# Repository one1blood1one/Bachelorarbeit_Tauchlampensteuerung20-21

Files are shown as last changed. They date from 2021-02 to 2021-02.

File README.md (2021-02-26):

Dieses Repository gehört zur Bachelorarbeit von Dennis Sitnic. 
Es enthält (nach der Fertigstellung) folgende Dateien:

**Unterlagen:**
- Bachelorarbeit PDF
- Präsentation der Arbeit
- Gebrauchsanleitung 

**Breakoutboard:**
- Eagle Daten
- Gerberdaten
- BOM

**Gesamtschaltung:**
- Eagle Daten
- Gerberdaten
- BOM

**Software:**
- Microcontroller Code
- Initialprogrammierung shell script

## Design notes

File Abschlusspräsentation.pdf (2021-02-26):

## Wintersemester 2020-21

Dennis Sitnic | 26.02.2021

# Abschlusspräsentation

# Entwicklung einer µC-Steuerung für Halogenbrenner mit LIB Management

Seite 2/31
26.02.2021

Entwicklung einer Tauchlampensteuerung Dennis Sitnic

# Gliederung

# 1. Einführung

# 2. Vorgehen und Ergebnis

## 1. Breakoutboard (BMS) 2. Steuerteil (µC) 3. Machbarkeitstests 4. Gesamtschaltung

# 3. Weiterführende Arbeiten

# 1 Einführung

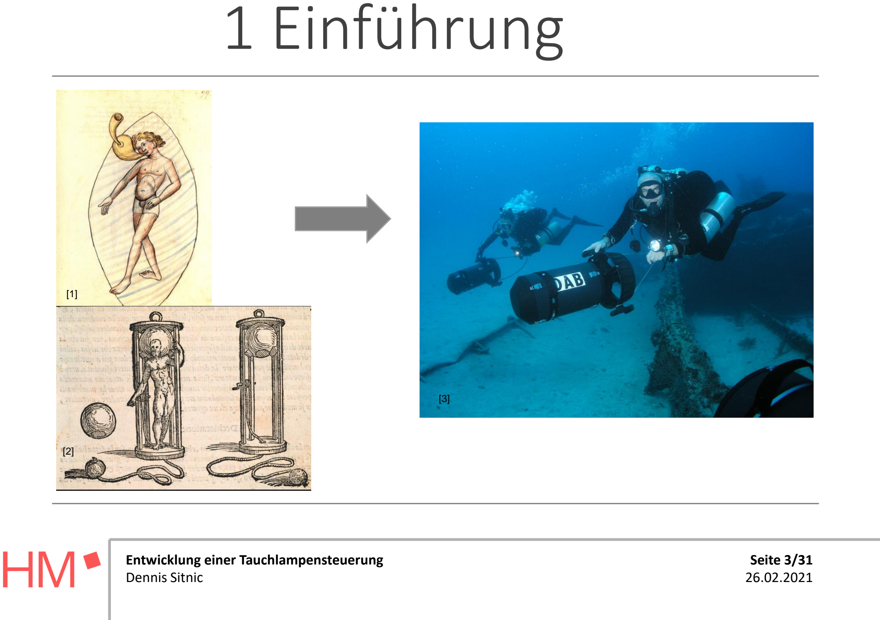
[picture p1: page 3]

Seite 3/31

Entwicklung einer Tauchlampensteuerung

[1]

[2]

[3]

Seite 4/31

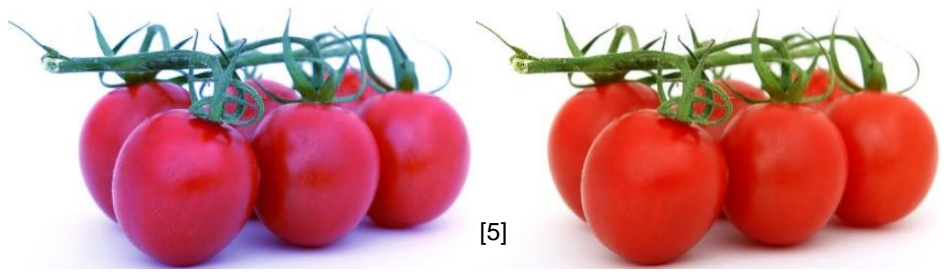
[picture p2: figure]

Entwicklung einer Tauchlampensteuerung

# 1 Einführung

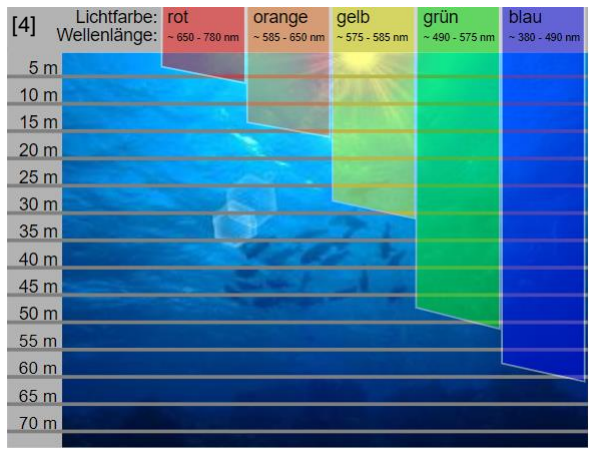
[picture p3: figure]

⚫ | rotes Licht dringt weniger tief ein
⚫ | Halogenlampen strahlen rotes Licht aus

Seite 5/31

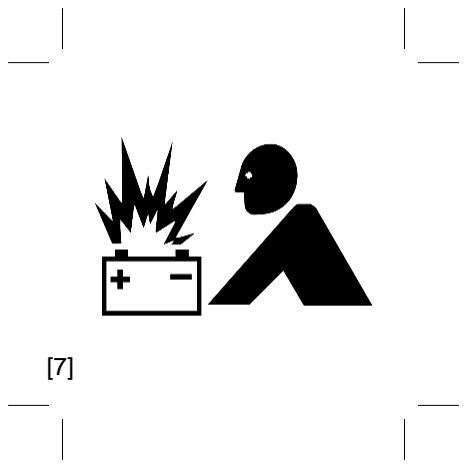
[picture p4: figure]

Entwicklung einer Tauchlampensteuerung

⚫ | Höhere Energiedichte bei geringerem Gewicht
⚫ | Müssen vor ungesunden Betriebszuständen geschützt werden
⚫ | Tiefentladung bei Lagerung von Tauchlampen

# 1 Einführung

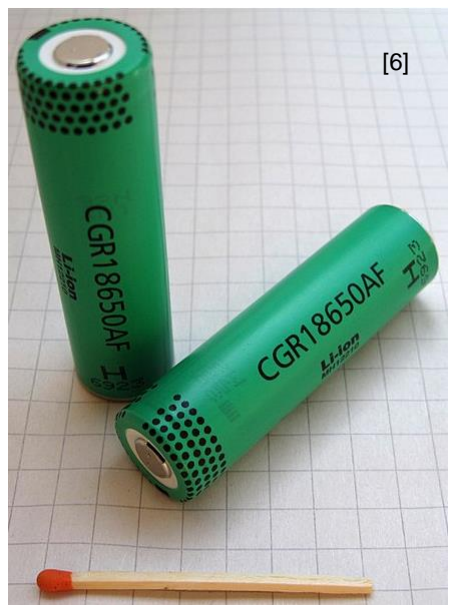
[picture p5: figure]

Nominalspannung: | 3,6 V
Ladeschlusspannung: | 4,2 V
Entladeschlusspannung: 2,5 V

Seite 6/31

Entwicklung einer Tauchlampensteuerung

# 1. Einführung

# 2. Vorgehen und Ergebnis

## 1. Breakoutboard 2. Steuerteil 3. Machbarkeitstests 4. Gesamtschaltung

# 3. Weiterführende Arbeiten

# Gliederung

Seite 7/31

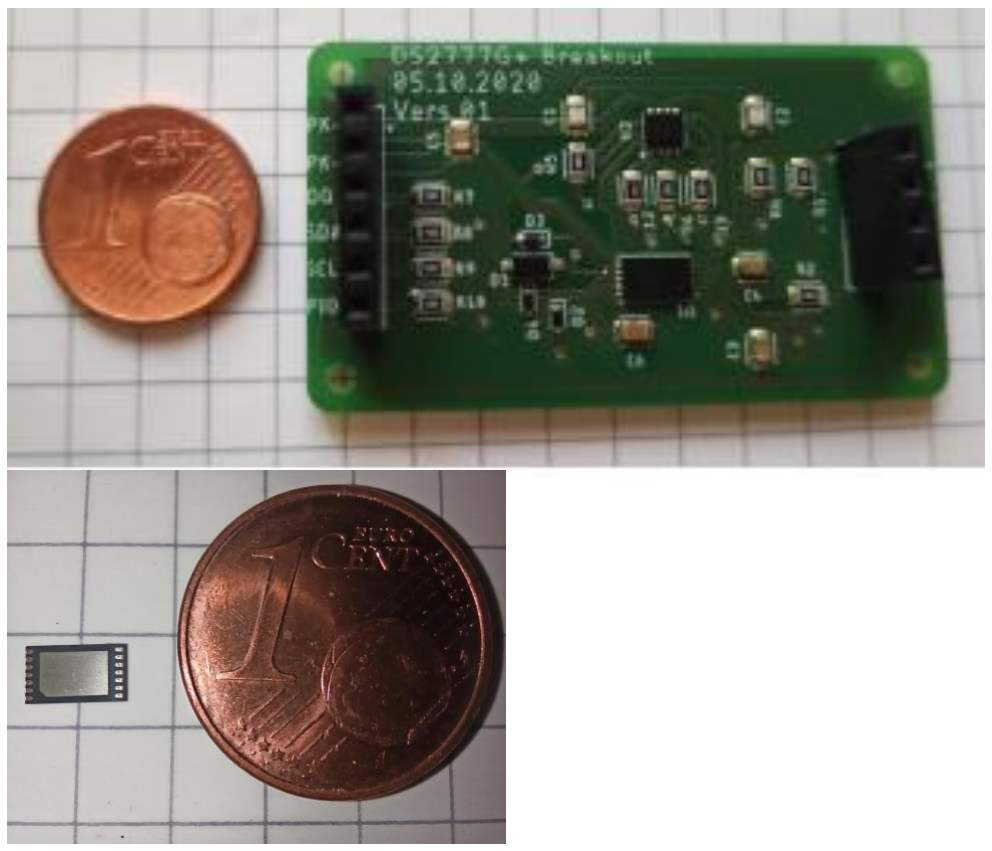
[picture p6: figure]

Entwicklung einer Tauchlampensteuerung

# 2.1 Entwicklung BMS-Teil

⚫ | BMS-Teil der Gesamtschaltung
⚫ | Misst „Echtzeitwerte“
⚫ | Jumwire Anschlüsse
⚫ | I2C Schnittstelle
⚫ | GPIO Pin
⚫ | Schwellwerte programmierbar
⚫ | Für 5 V als auch 3,3 V
⚫ | Sleep: 74 µA

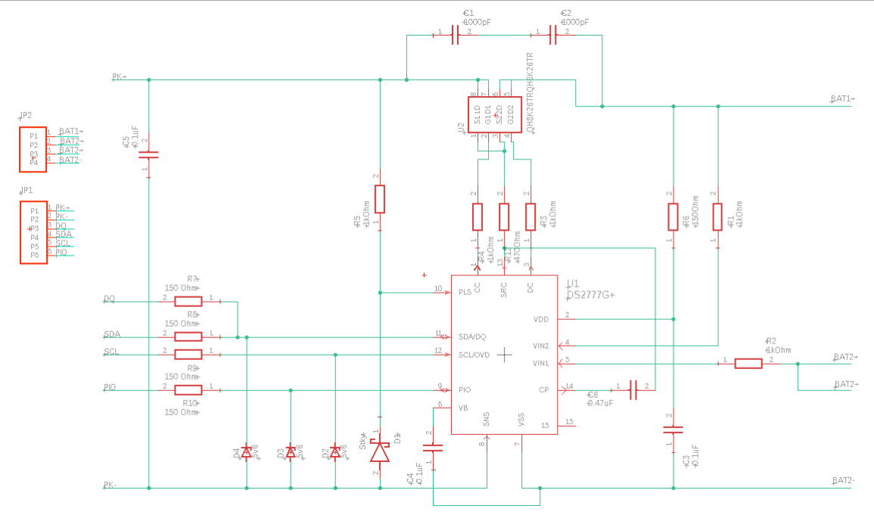
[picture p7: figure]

Seite 8/31

Entwicklung einer Tauchlampensteuerung

# 2.1 Entwicklung BMS-Teil

Seite 9/31

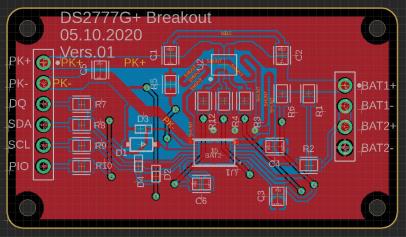
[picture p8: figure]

Entwicklung einer Tauchlampensteuerung

# 2.1 Entwicklung BMS-Teil

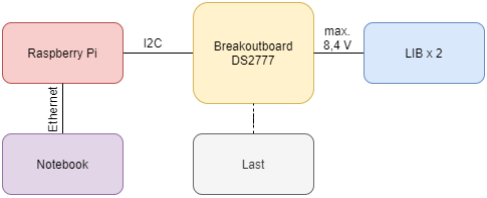
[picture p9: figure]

Seite 10/31

Entwicklung einer Tauchlampensteuerung

# 2.1 Entwicklung BMS-Teil

# 2.1 Entwicklung BMS-Teil

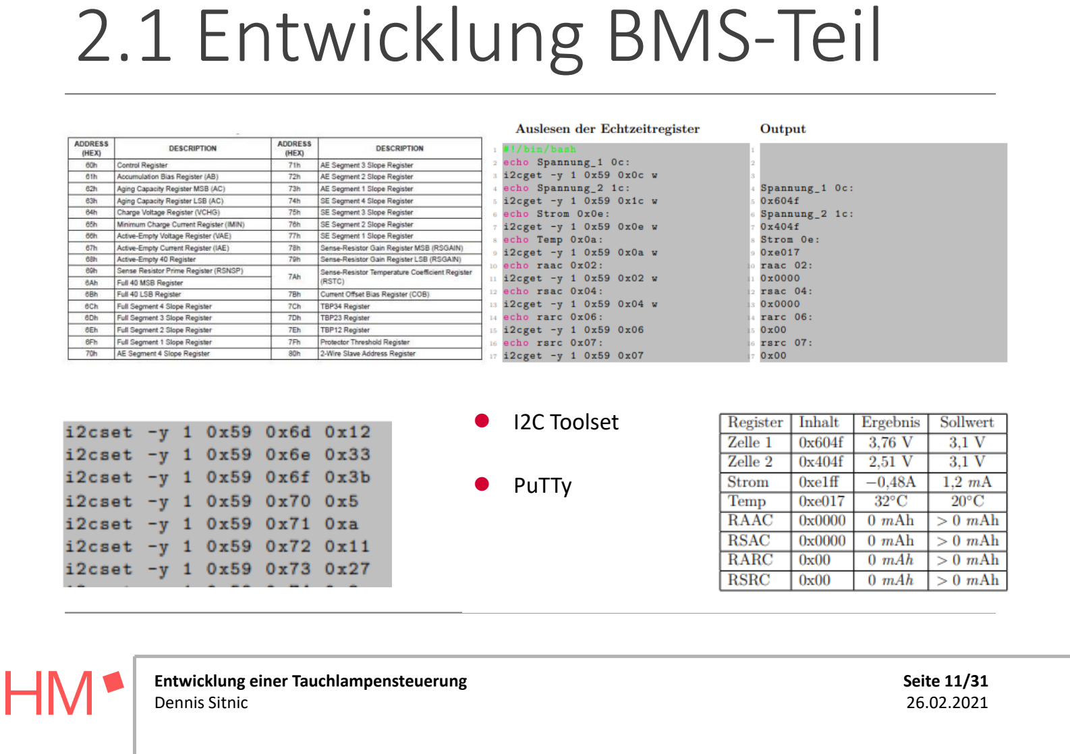
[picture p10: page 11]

Seite 11/31

Entwicklung einer Tauchlampensteuerung

⚫ | I2C Toolset
⚫ | PuTTy

Seite 12/31

Entwicklung einer Tauchlampensteuerung

# 1. Einführung

# 2. Vorgehen und Ergebnis

## 1. Breakoutboard 2. Steuerteil 3. Machbarkeitstests 4. Gesamtschaltung

# 3. Weiterführende Arbeiten

# Gliederung

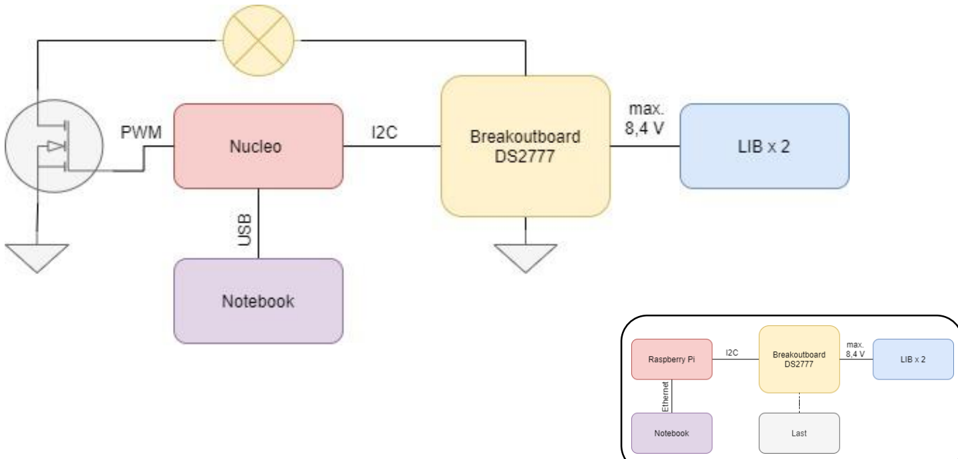
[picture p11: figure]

Seite 13/31

Entwicklung einer Tauchlampensteuerung

# 2.2 Entwicklung Steuerteil

Seite 14/31

Entwicklung einer Tauchlampensteuerung

# 2.2 Entwicklung Steuerteil

⚫ | PWM Signal initialisieren
⚫ | Poti einlesen
⚫ | CCR verändern

Seite 15/31

Entwicklung einer Tauchlampensteuerung

# 2.2 Entwicklung Steuerteil

⚫ | Messwerte lesen
⚫ | Messwerte ausgeben

Seite 16/31

Entwicklung einer Tauchlampensteuerung

# 1. Einführung

# 2. Vorgehen und Ergebnis

## 1. Breakoutboard 2. Steuerteil 3. Machbarkeitstests 4. Gesamtschaltung

# 3. Weiterführende Arbeiten

# Gliederung

Seite 17/31

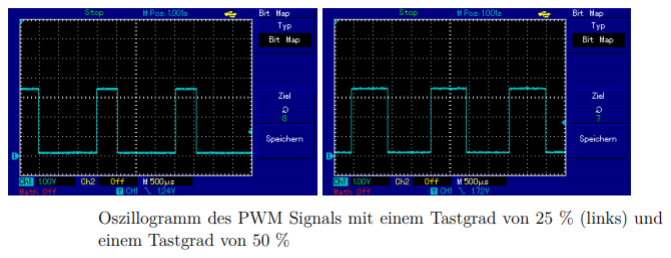
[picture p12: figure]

Entwicklung einer Tauchlampensteuerung

# 2.3 Machbarkeitsstudie

# ⚫ PWM Signal

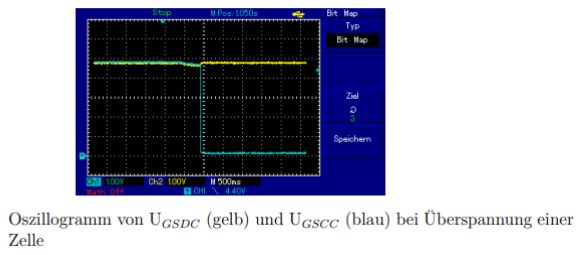
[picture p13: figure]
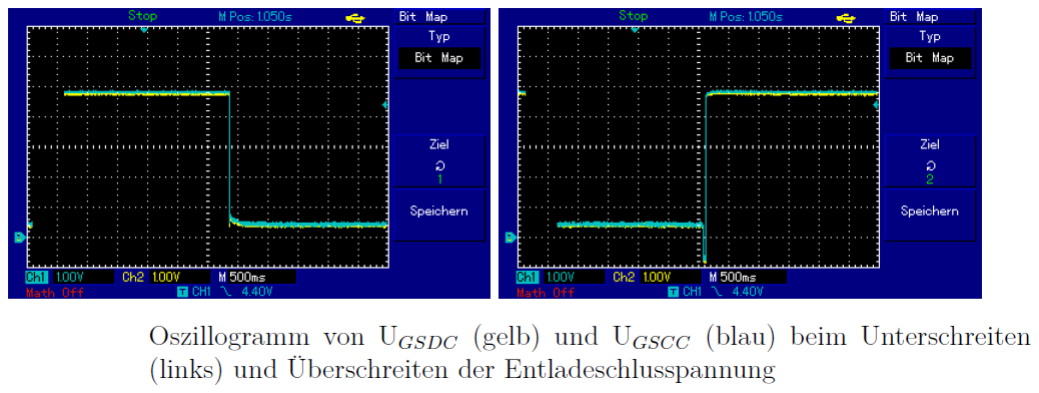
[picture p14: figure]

Seite 18/31

Entwicklung einer Tauchlampensteuerung

## ⚫ Overvoltage 4,2 V

## ⚫ Undervoltage 2,6 V

# 2.3 Machbarkeitsstudie

Seite 19/31

Entwicklung einer Tauchlampensteuerung

# Gliederung

# 1. Einführung

# 2. Vorgehen und Ergebnis

## 1. Breakoutboard 2. Steuerteil 3. Machbarkeitstests 4. Gesamtschaltung

# 3. Weiterführende Arbeiten

Seite 20/31

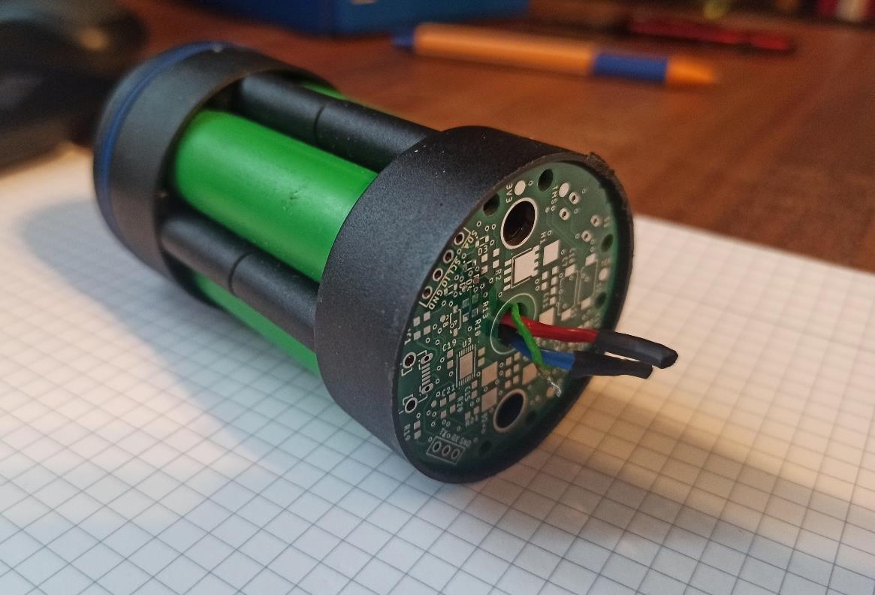
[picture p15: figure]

Entwicklung einer Tauchlampensteuerung

# 2.4 Gesamtschaltung

⚫ | BMS-Integriert (aus 2.1)
⚫ | USB, SWD programmierbar
⚫ | GPIOs, UART, I2C, USB, SWD
⚫ | Anschluss Ladeteil
⚫ | Testpunkte, Pins, Schalter
⚫ | 4 € für 5 PCBs
⚫ | Geringer Verbrauch

Seite 21/31

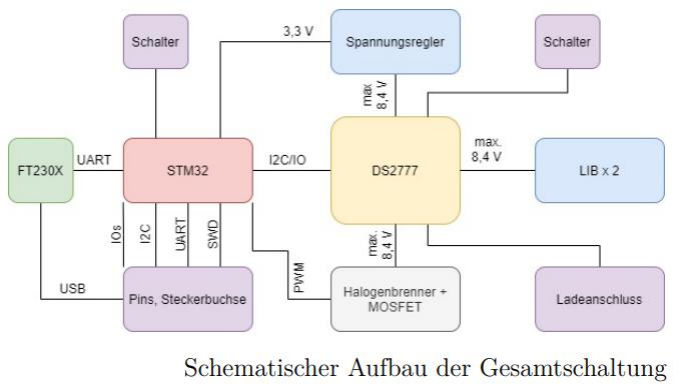
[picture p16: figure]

Entwicklung einer Tauchlampensteuerung

# 2.4 Gesamtschaltung

# 2.4 Gesamtschaltung

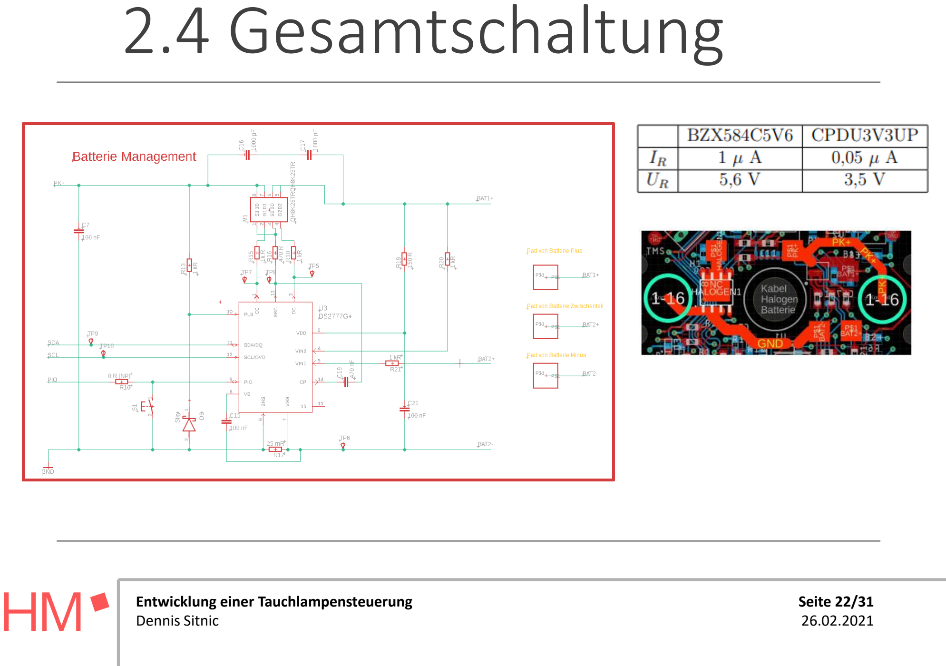
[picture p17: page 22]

Seite 22/31

Entwicklung einer Tauchlampensteuerung

Seite 23/31

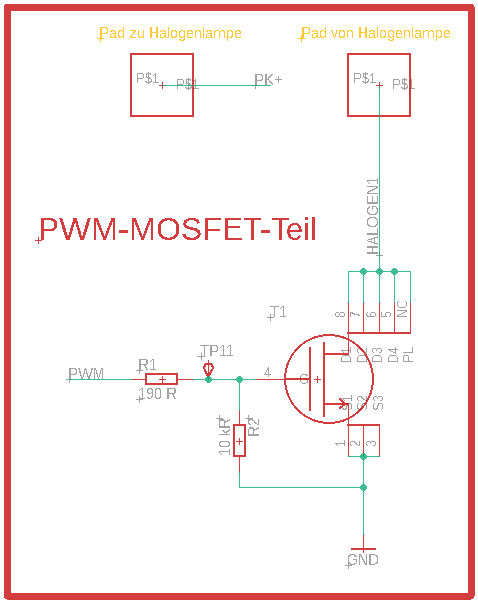
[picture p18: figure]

Entwicklung einer Tauchlampensteuerung

# 2.4 Gesamtschaltung

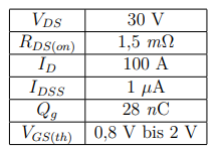
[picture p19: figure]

Seite 24/31

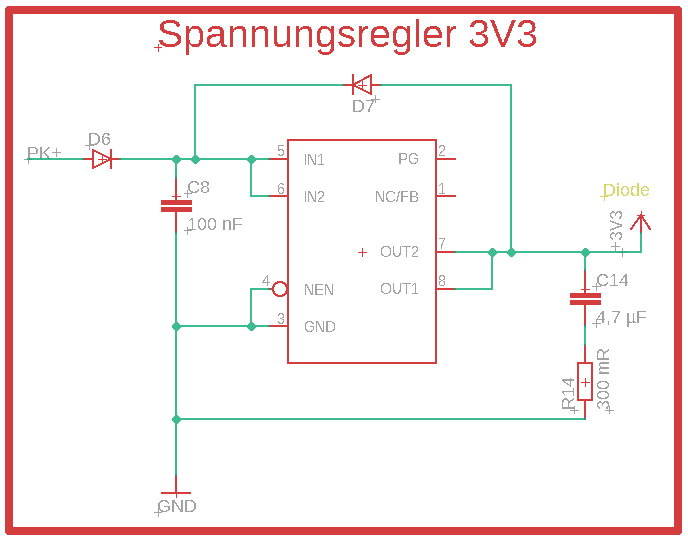
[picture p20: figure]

Entwicklung einer Tauchlampensteuerung

# 2.4 Gesamtschaltung

Seite 25/31

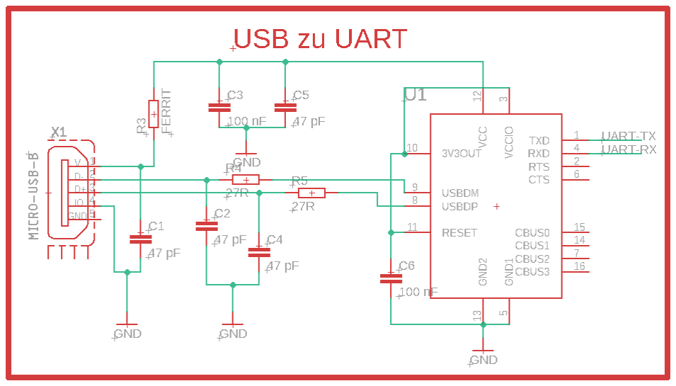
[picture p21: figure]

Entwicklung einer Tauchlampensteuerung

# 2.4 Gesamtschaltung

Seite 26/31

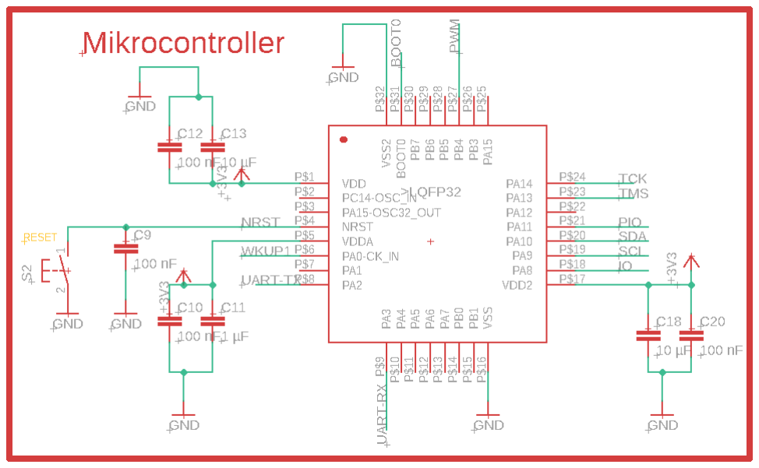
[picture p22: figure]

Entwicklung einer Tauchlampensteuerung

# 2.4 Gesamtschaltung

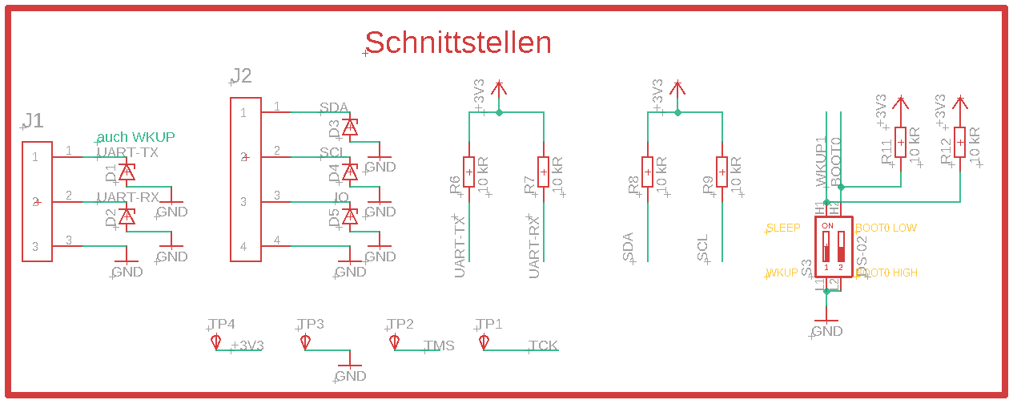
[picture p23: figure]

Seite 27/31

Entwicklung einer Tauchlampensteuerung

# 2.4 Gesamtschaltung

Seite 28/31

Entwicklung einer Tauchlampensteuerung

# Gliederung

# 1. Einführung

# 2. Vorgehen und Ergebnis

## 1. Breakoutboard 2. Steuerteil 3. Machbarkeitstests 4. Gesamtschaltung

# 3. Weiterführende Arbeiten

Seite 29/31

Entwicklung einer Tauchlampensteuerung

# 3 Weiterführende Arbeiten

# ⚫ Bestücken und Inbetriebnahme

# ⚫ Optimierung – SW anpassen – Überflüssige Elemente beseitigen

Seite 30/31

Entwicklung einer Tauchlampensteuerung

# 3 Weiterführende Arbeiten

# ⚫ Bedienelement

# – Anzeige Messdaten – Steuerung Sleep, Active – Dimmen – Ladekontakt

Seite 31/31

Entwicklung einer Tauchlampensteuerung

⚫ | https://github.com/one1blood1one/Bachelorarbeit_Tauchlampensteuerung20-21
| – Eagle Schaltplan und Layout – Gerberdaten – BOM – Code: µC, DS2777 – Bachelorarbeit PDF – ggf. Gebrauchsanweisung

# 3 Weiterführende Arbeiten

## Vielen Dank für Ihre Aufmerksamkeit!

# Abschlusspräsentation

# Entwicklung einer Tauchlampensteuerung

# Fragen ?

Seite 34/31

Entwicklung einer Tauchlampensteuerung

# Quellen

⚫ | [1] Unknown illustrator, Public domain, via Wikimedia Commons, gemeinfrei, (https://de.wikipedia.org/wiki/Gemeinfreiheit) weil urheberrechtliche Schutzfrist abgelaufen ist (15th Century)
⚫ | [2] Unknown illustrator, Public domain, via Wikimedia Commons, gemeinfrei, (https://de.wikipedia.org/wiki/Gemeinfreiheit) weil urheberrechtliche Schutzfrist abgelaufen ist (16th Century)
⚫ | [3] Matthew Hoelscher from Doral, FL, USA, CC BY-SA 2.0 <https://creativecommons.org/licenses/by-sa/2.0>, via Wikimedia Commons
⚫ | [4] Thomei08, CC BY-SA 3.0 <https://creativecommons.org/licenses/by-sa/3.0>, via Wikimedia Commons
⚫ | [5] Shutterbug75, https://pixabay.com/de/vectors/batterie-explosion-warnung-gefahr-98707/
⚫ | [6] Lead holder, CC BY-SA 3.0 <https://creativecommons.org/licenses/by-sa/3.0>, via Wikimedia Commons
⚫ | [7] Openicons, https://pixabay.com/de/vectors/batterie-explosion-warnung-gefahr-98707/
⚫ | Alle Interntseiten wurden zuletzt am 25.02.21 aufgerufen

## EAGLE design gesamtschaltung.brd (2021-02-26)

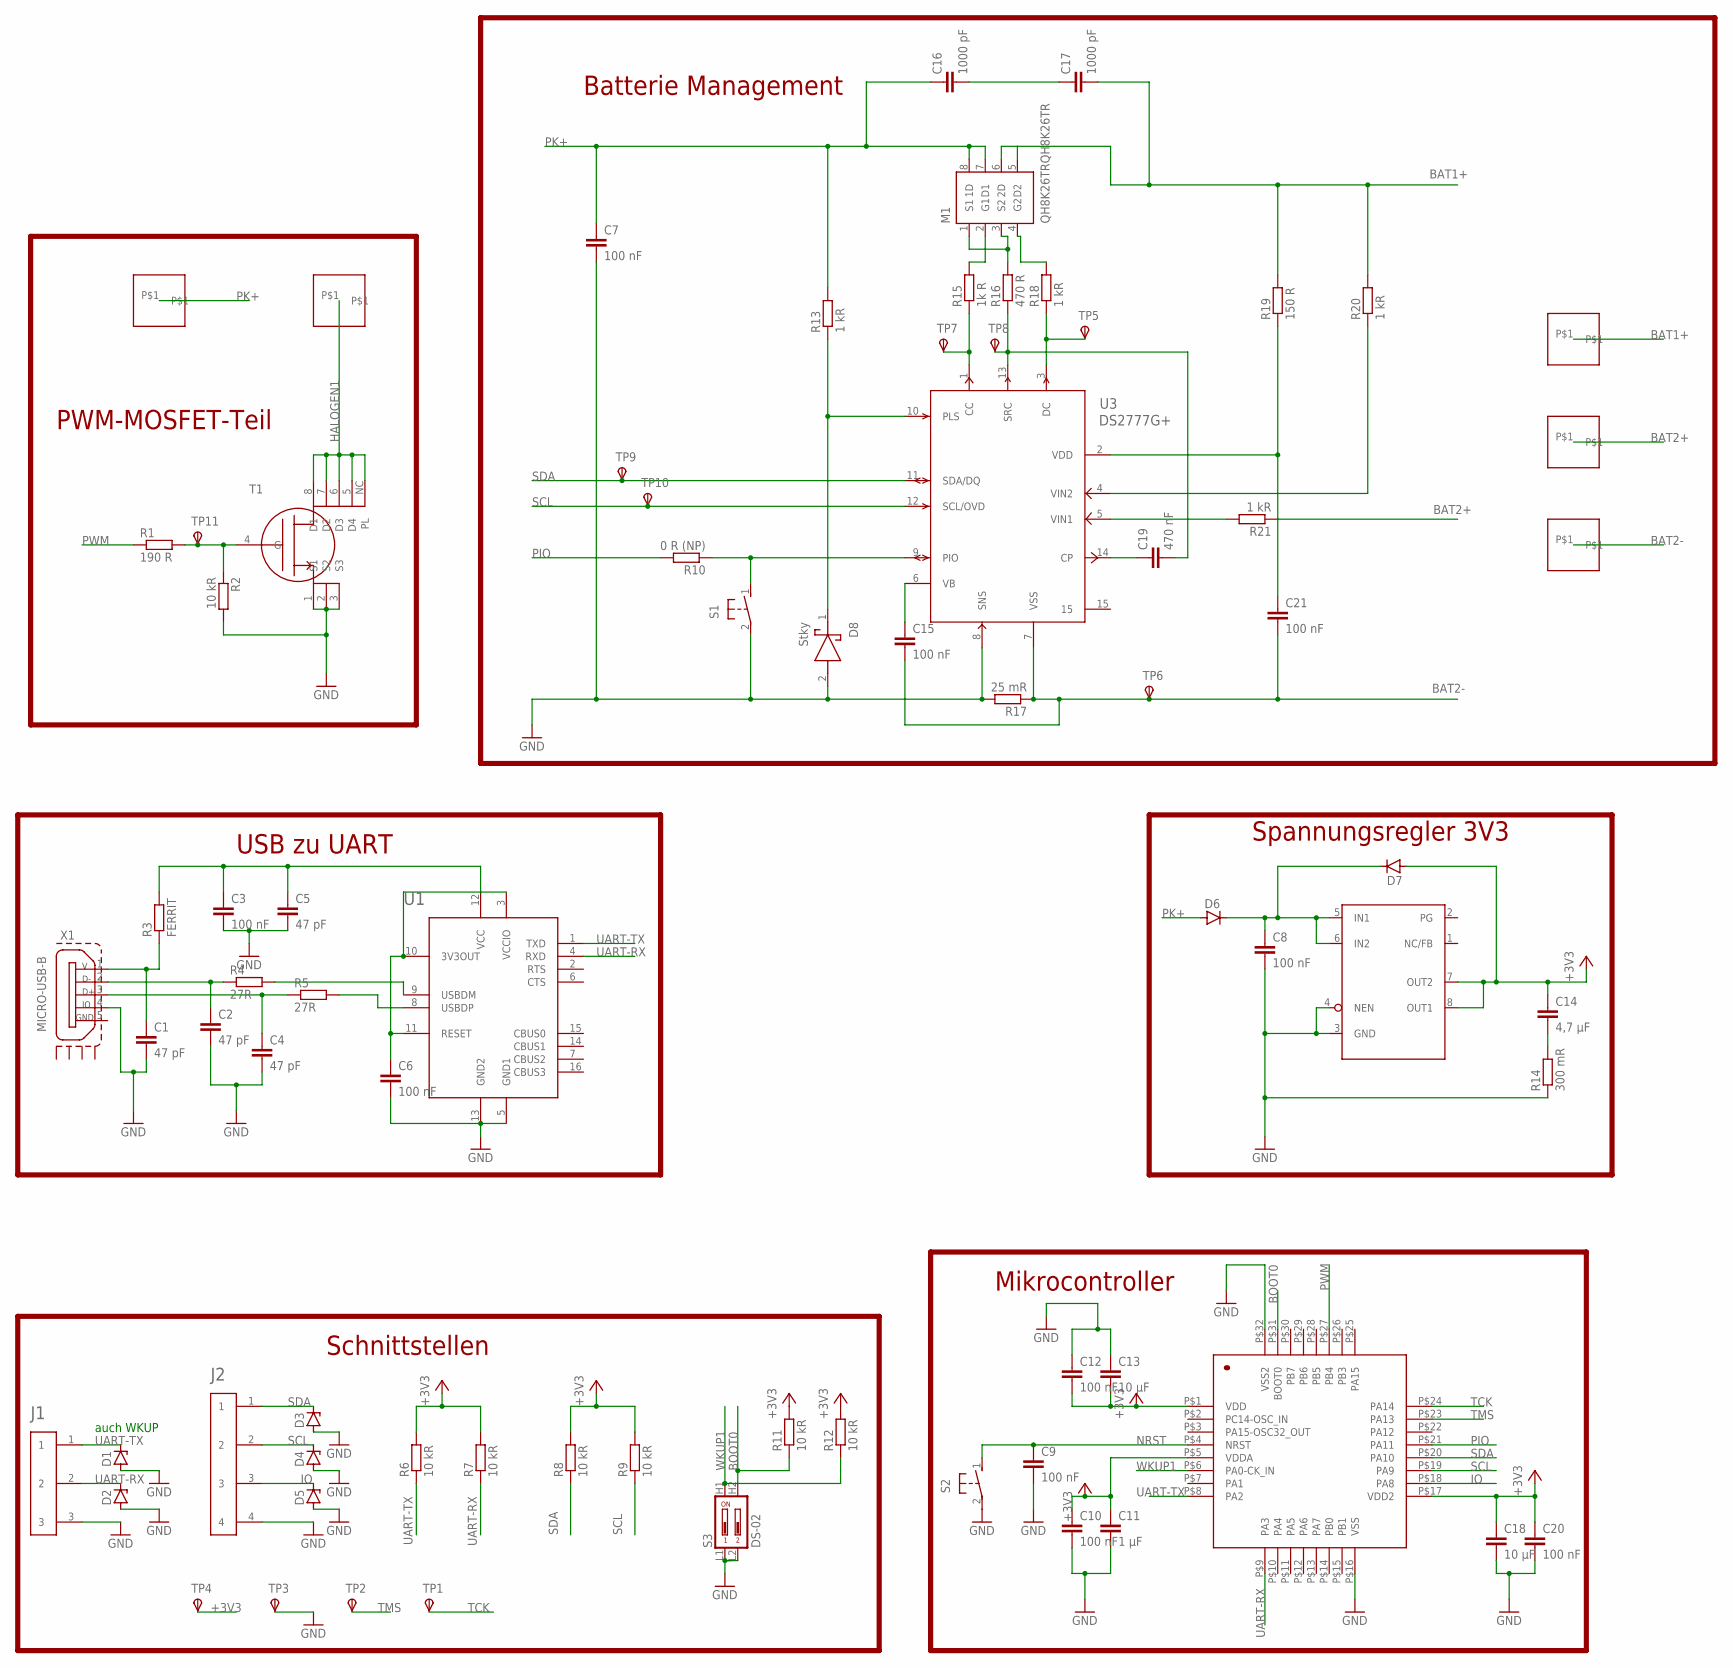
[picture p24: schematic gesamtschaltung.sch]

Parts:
C1, C2, C4, C5: 47 pF; C0603
C3, C6, C7, C8, C9, C10, C12, C15, C20, C21: 100 nF; C0603
C11: 1 µF; C0603
C13, C18: 10 µF; C0603
C14: 4,7 µF; C0603
C16, C17: 1000 pF; C0603
C19: 470 nF; C0603
D1, D2, D3, D4, D5: TVS-3V5; TVS-FOOT
D6, D7: DIODE-SILIZIUM; TVS-FOOT
D8: Stky; SOD3715X135N
J1: 3PIN; HDRV3W64P254_1X3_762X254X854B
J2: 4PIN-MALE; 4P-MALE-FOOT
M1: QH8K26TRQH8K26TR; SOTFL65P280X85-8N
MC1: STM32L031K6T6; LQFP32
P1, P2, P3, P4, P5: PAD-3MM
R1: 190 R; R0603
R2, R6, R7, R8, R9, R11, R12: 10 kR; R0603
R3: FERRIT; R0603
R4, R5: 27R; R0603
R10: 0 R (NP); R0603
R13, R18, R20, R21: 1 kR; R0603
R14: 300 mR; R0603
R15: 1k R; R0603
R16: 470 R; R0603
R17: 25 mR; R0603
R19: 150 R; R0603
S1, S2: BUTTON
S3: DS-02
T1: POWER-MOS; SO-8
TP1, TP2, TP3, TP4: TPSTP20R; TP20R
TP5, TP6, TP7, TP8, TP9, TP10, TP11: TPSTP10R; TP10R
U1: FT230X; SSOP16
U2: TPS76633DR; TPS766FOOTPRINT
U3: DS2777G+; DS2777_TDFN-15-OWN
X1: MICRO-USB-B; MICROUSBFOOT

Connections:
+3V3: C10.1, C11.1, C12.2, C13.2, C14.1, C18.1, C20.1, D7.A, MC1.P$1 (VDD), MC1.P$5 (VDDA), MC1.P$17 (VDD2), R6.2, R7.2, R8.2, R9.2, R11.2, R12.2, TP4.TP, U2.7 (OUT2), U2.8 (OUT1)
BAT1+: C17.2, M1.5 (D2), M1.6 (2D), P3.P$1, R19.2, R20.2
BAT2+: P4.P$1, R21.1
BAT2-: C15.2, C21.2, P5.P$1, R17.1, TP6.TP, U3.7 (VSS)
BOOT0: MC1.P$31 (BOOT0), R11.1, S3.H2
GND: C1.2, C2.2, C3.2, C4.2, C5.2, C6.2, C7.2, C8.2, C9.2, C10.2, C11.2, C12.1, C13.1, C18.2, C20.2, D1.A, D2.A, D3.A, D4.A, D5.A, D8.2 (A), J1.3, J2.4, MC1.P$16 (VSS), MC1.P$32 (VSS2), R2.2, R14.1, R17.2, S1.2 (L), S2.2 (L), S3.L1, S3.L2, T1.1 (S1), T1.2 (S2), T1.3 (S3), TP3.TP, U1.5 (GND1), U1.13 (GND2), U2.3 (GND), U2.4 (NEN), U3.8 (SNS), X1.4 (IO)
HALOGEN1: P2.P$1, T1.5 (D4), T1.6 (D3), T1.7 (D2), T1.8 (D1), T1.NC (PL)
IO: D5.K, J2.3, MC1.P$18 (PA8)
unnamed: R21.2, U3.5 (VIN1)
unnamed: R20.1, U3.4 (VIN2)
unnamed: C21.1, R19.1, U3.2 (VDD)
unnamed: C3.1, C5.1, R3.2, U1.12 (VCC)
unnamed: R1.2, R2.1, T1.4 (G), TP11.TP
unnamed: R4.2, U1.9 (USBDM)
unnamed: R15.1, TP7.TP, U3.1 (CC)
unnamed: C19.2, R16.1, TP8.TP, U3.13 (SRC)
unnamed: R18.1, TP5.TP, U3.3 (DC)
unnamed: M1.2 (G1), R15.2
unnamed: M1.4 (G2), R18.2
unnamed: M1.1 (S1), M1.3 (S2), R16.2
unnamed: C15.1, U3.6 (VB)
unnamed: C4.1, R5.1, X1.3 (D+)
unnamed: C16.2, C17.1
unnamed: C19.1, U3.14 (CP)
unnamed: D8.1 (K), R13.1, U3.10 (PLS)
unnamed: C8.1, D6.K, D7.K, U2.5 (IN1), U2.6 (IN2)
unnamed: C2.1, R4.1, X1.2 (D-)
unnamed: C14.2, R14.2
unnamed: R5.2, U1.8 (USBDP)
unnamed: C6.1, U1.3 (VCCIO), U1.10 (3V3OUT), U1.11 (RESET)
unnamed: C1.1, R3.1, X1.1 (V)
NRST: C9.1, MC1.P$4 (NRST), S2.1 (H)
PIO: MC1.P$21 (PA11), R10.2
PIO1: R10.1, S1.1 (H), U3.9 (PIO)
PK+: C7.1, C16.1, D6.A, M1.7 (D1), M1.8 (1D), P1.P$1, R13.2
PWM: MC1.P$27 (PB4), R1.1
SCL: D4.K, J2.2, MC1.P$19 (PA9), R9.1, TP10.TP, U3.12 (SCL/OVD)
SDA: D3.K, J2.1, MC1.P$20 (PA10), R8.1, TP9.TP, U3.11 (SDA/DQ)
TCK: MC1.P$24 (PA14), TP1.TP
TMS: MC1.P$23 (PA13), TP2.TP
UART-RX: D2.K, J1.2, MC1.P$9 (PA3), R7.1, U1.4 (RXD)
UART-TX: D1.K, J1.1, MC1.P$8 (PA2), R6.1, U1.1 (TXD)
WKUP1: MC1.P$6 (PA0-CK_IN), R12.1, S3.H1

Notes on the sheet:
auch WKUP
USB zu UART
Mikrocontroller
Spannungsregler 3V3
PWM-MOSFET-Teil
Batterie Management
Schnittstellen

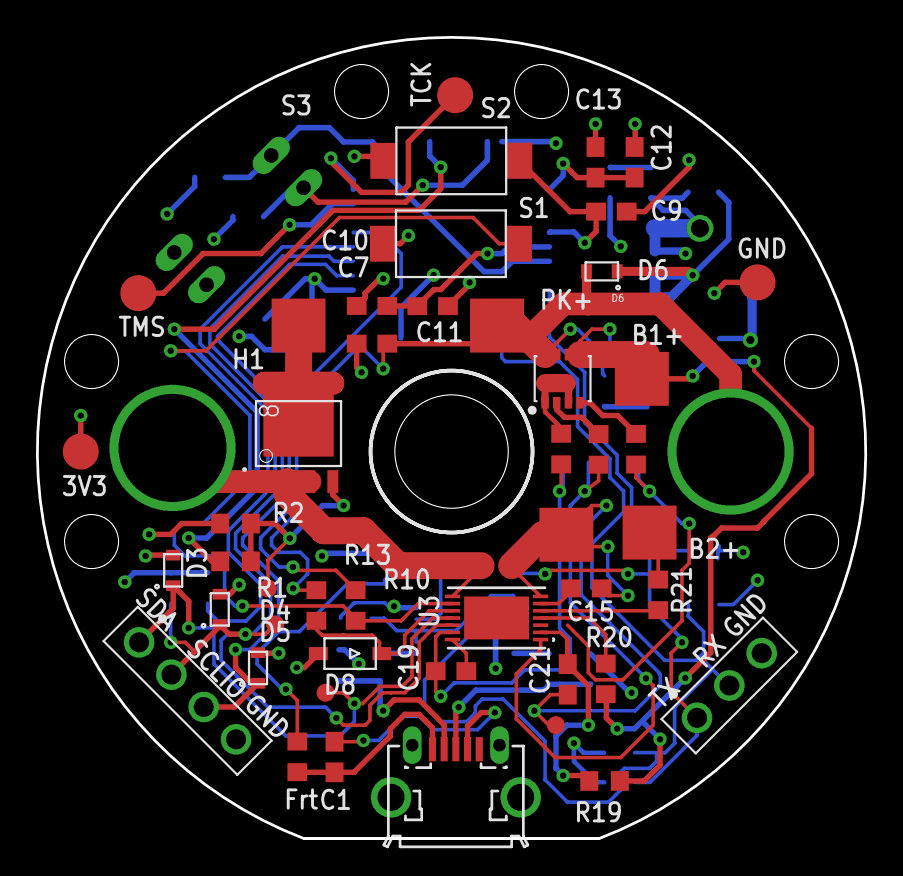
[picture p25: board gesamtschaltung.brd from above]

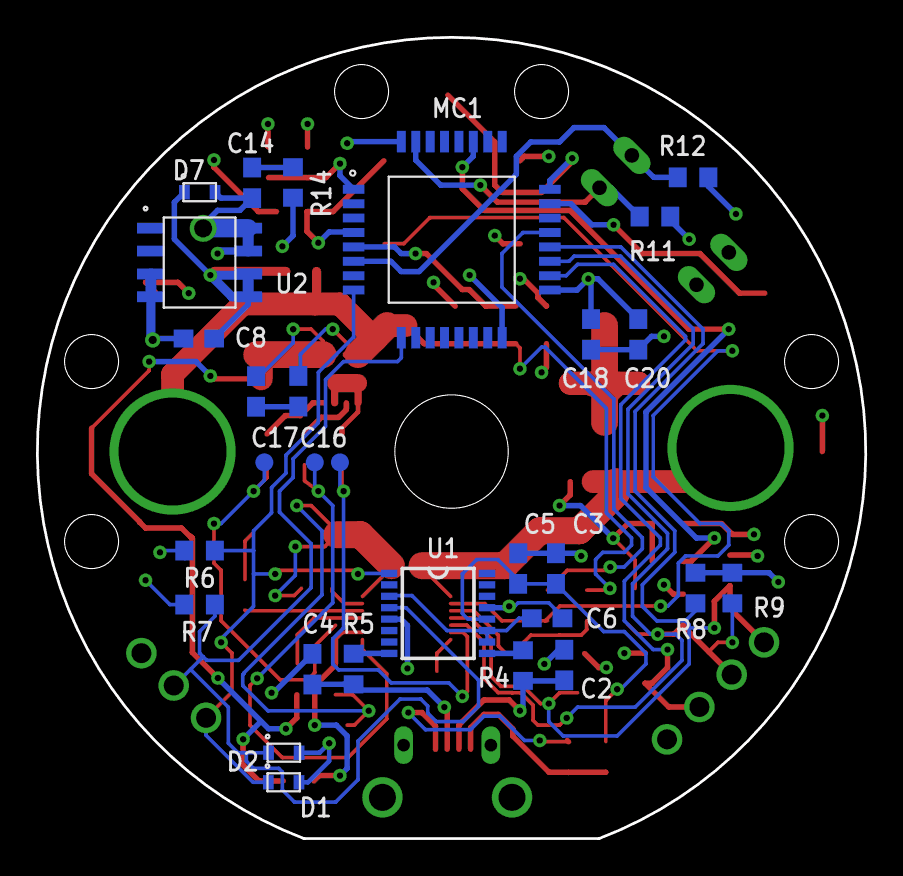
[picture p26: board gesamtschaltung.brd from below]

Board: 4 copper layers, 46.0 x 44.5 mm, 78 parts (29 on the bottom side), 43 nets.

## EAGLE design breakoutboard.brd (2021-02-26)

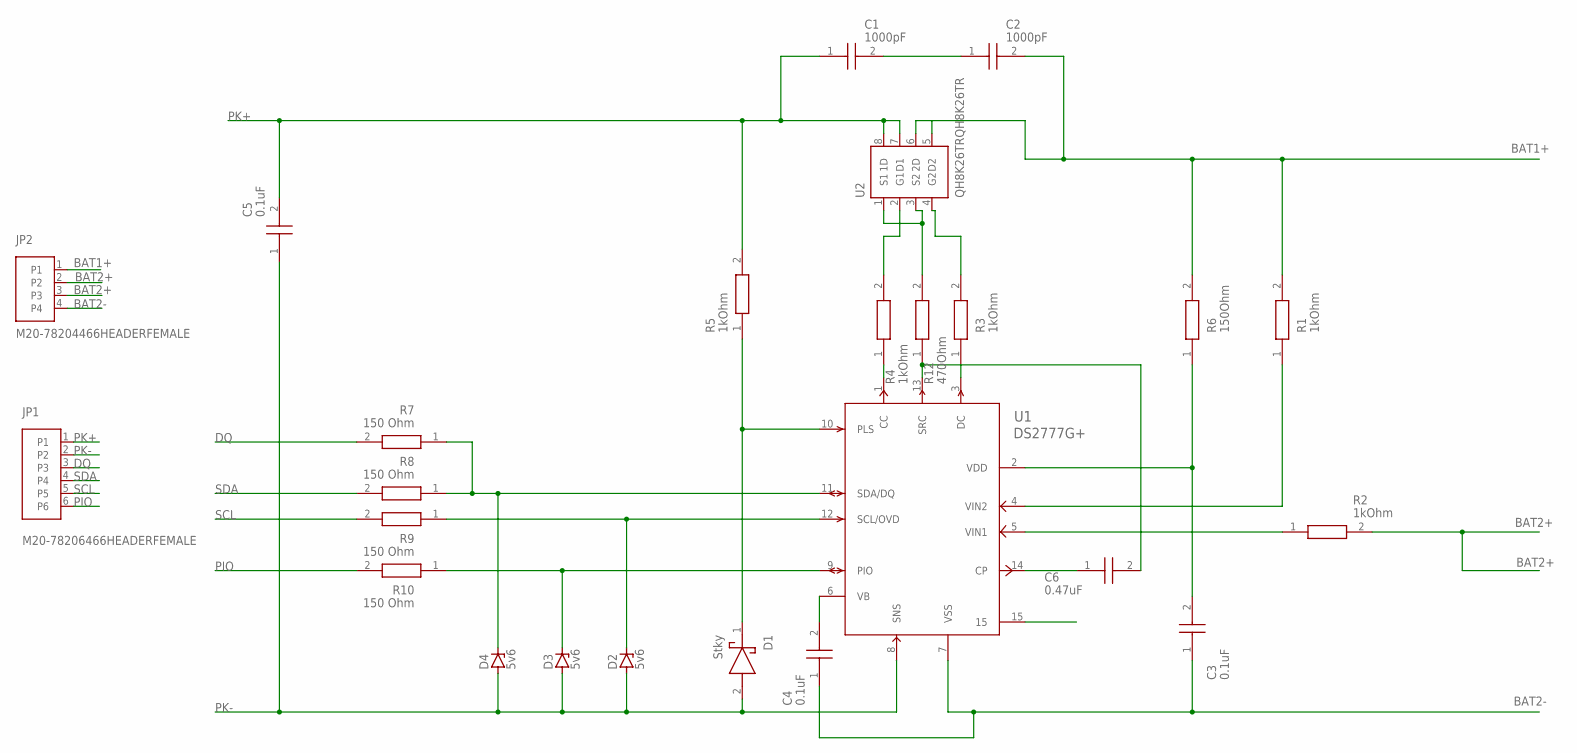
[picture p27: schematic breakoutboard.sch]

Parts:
C1, C2: 1000pF; CAPC2012X100N
C3, C4, C5: 0.1uF; CAPC2012X100N
C6: 0.47uF; CAPC2012X100N
D1: Stky; SOD3715X135N
D2, D3, D4: 5v6; SODFL1608X75N
JP1: M20-78206466HEADERFEMALE; HDRVR6W65P254_1X6_1564X250X865B
JP2: M20-78204466HEADERFEMALE; HDRVR4W65P254_1X4_1056X250X865B
R1, R2, R3, R4, R5: 1kOhm; RESC2012X70N
R6: 150Ohm; RESC2012X70N
R7, R8, R9, R10: 150 Ohm; RESC2012X70N
R12: 470Ohm; RESC2012X70N
U1: DS2777G+; DS2777_TDFN-15-OWN
U2: QH8K26TRQH8K26TR; SOTFL65P280X85-8N

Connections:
BAT1+: C2.2, JP2.1, R1.2, R6.2, U2.5 (D2), U2.6 (2D)
BAT2+: JP2.2, JP2.3, R2.2
BAT2-: C3.1, C4.1, JP2.4, U1.7 (VSS), U1.15
DQ: JP1.3, R7.2
unnamed: R2.1, U1.5 (VIN1)
unnamed: R1.1, U1.4 (VIN2)
unnamed: C3.2, R6.1, U1.2 (VDD)
unnamed: R4.1, U1.1 (CC)
unnamed: C6.2, R12.1, U1.13 (SRC)
unnamed: R3.1, U1.3 (DC)
unnamed: R4.2, U2.2 (G1)
unnamed: R3.2, U2.4 (G2)
unnamed: R12.2, U2.1 (S1), U2.3 (S2)
unnamed: C4.2, U1.6 (VB)
unnamed: C1.2, C2.1
unnamed: D4.1 (K), R7.1, R8.1, U1.11 (SDA/DQ)
unnamed: C6.1, U1.14 (CP)
unnamed: D1.1 (K), R5.1, U1.10 (PLS)
unnamed: D2.1 (K), R9.1, U1.12 (SCL/OVD)
unnamed: D3.1 (K), R10.1, U1.9 (PIO)
PIO: JP1.6, R10.2
PK+: C1.1, C5.2, JP1.1, R5.2, U2.7 (D1), U2.8 (1D)
PK-: C5.1, D1.2 (A), D2.2 (A), D3.2 (A), D4.2 (A), JP1.2, U1.8 (SNS)
SCL: JP1.5, R9.2
SDA: JP1.4, R8.2

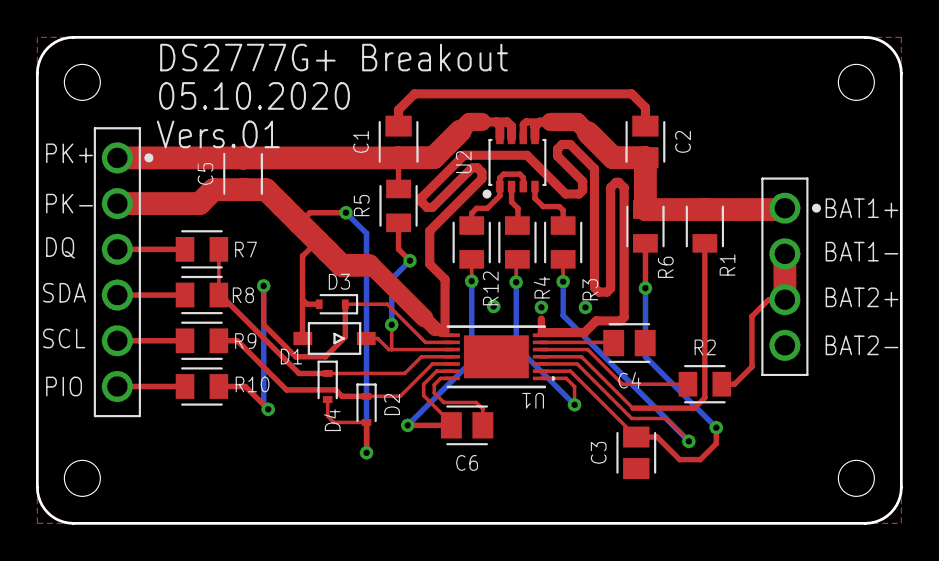
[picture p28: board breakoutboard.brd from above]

Board: 2 copper layers, 48.0 x 27.0 mm, 25 parts (0 on the bottom side), 25 nets.
